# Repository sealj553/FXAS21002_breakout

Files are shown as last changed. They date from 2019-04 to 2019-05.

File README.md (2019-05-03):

# FXAS21002 breakout

This is a modified version of [William Laney's breakout](https://github.com/WLaney/FXAS21002-gyro-PCB) designed to be as small as possible.

Note: The SAO pin is pulled to GND, so the I2C address will be 0x20. If you are using a library that hardcodes the address to 0x21 (Adafruit's for instance), you may need to modify it.

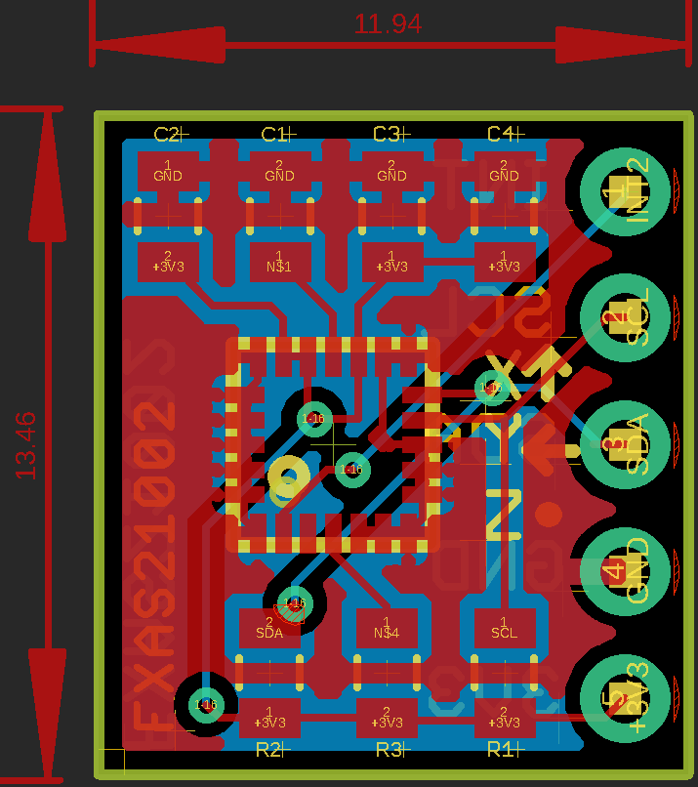
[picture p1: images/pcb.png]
pcb PCB

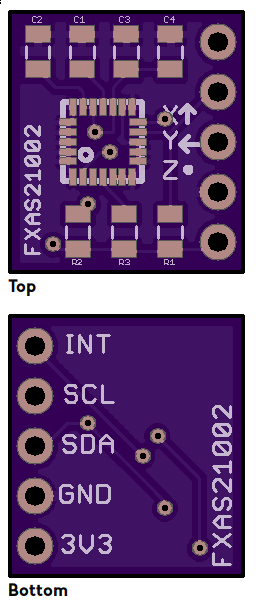
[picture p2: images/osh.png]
osh OSH Park


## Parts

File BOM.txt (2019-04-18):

component/value, size, quanity, digikey part number
--------------------------------------------------------
FXAS21002 IC, 24-TFQFN, 1, FXAS21002CQR1CT-ND
10K resistor, 0805, 2, 311-10.0KCRCT-ND
47k resistor, 0805, 1, 	311-47KARCT-ND
0.1uF capacitor, 0805, 3, 478-3755-1-ND
1.0uF capacitor, 0805, 1 311-1365-1-ND

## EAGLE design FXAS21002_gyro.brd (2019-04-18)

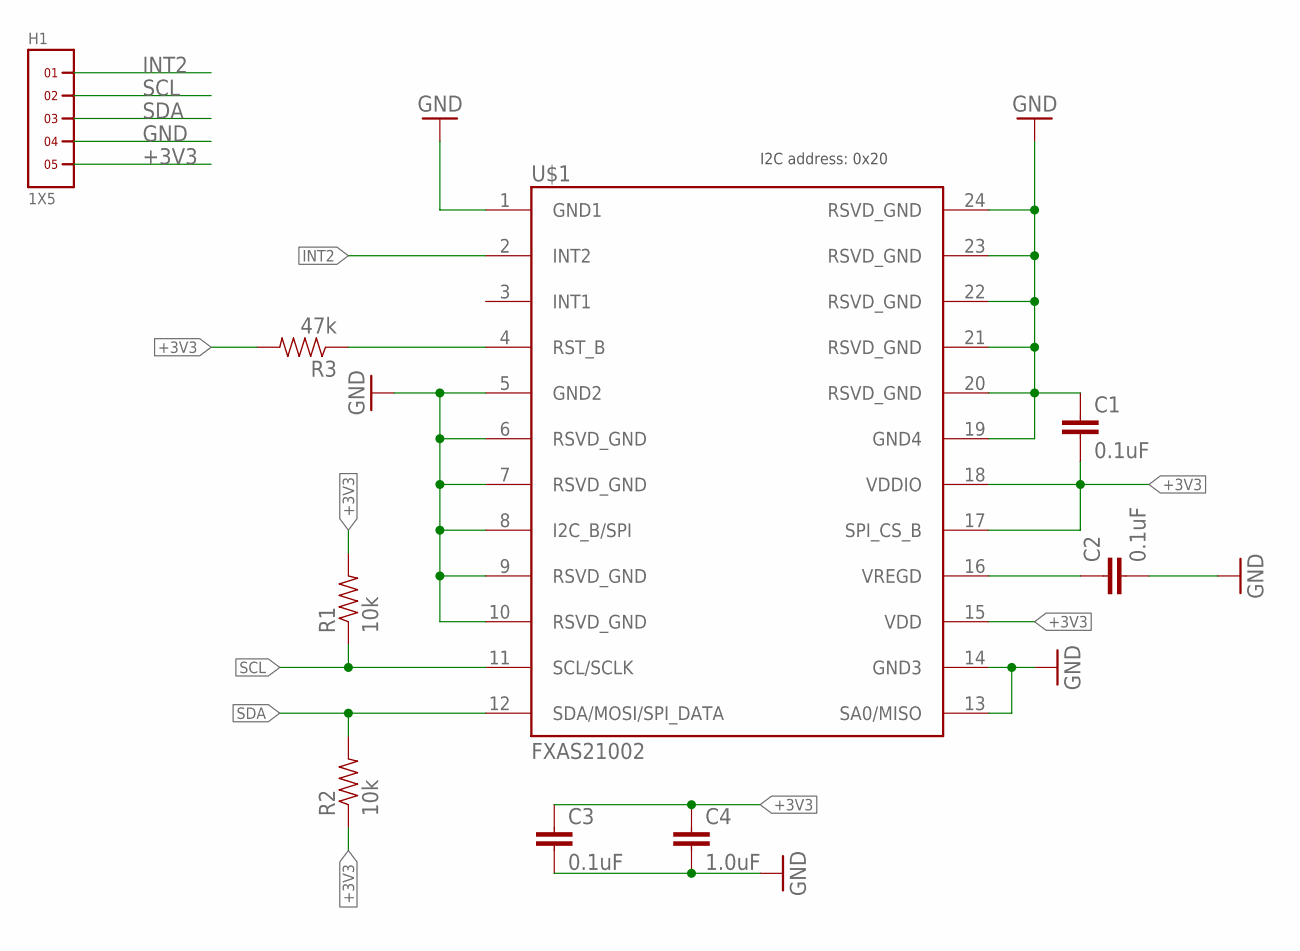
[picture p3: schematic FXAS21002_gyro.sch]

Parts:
C1, C2, C3: 0.1uF; 0805
C4: 1.0uF; 0805
H1: 1X5
R1, R2: 10k; 0805
R3: 47k; 0805
U$1: FXAS21002; 24QFN

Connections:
+3V3: C1.2, C3.1, C4.1, H1.5, R1.2, R2.1, R3.2, U$1.15 (VDD), U$1.17 (SPI_CS_B), U$1.18 (VDDIO)
GND: C1.1, C2.2, C3.2, C4.2, H1.4, U$1.1 (GND1), U$1.5 (GND2), U$1.6 (RSVD_GND), U$1.7 (RSVD_GND), U$1.8 (I2C_B/SPI), U$1.9 (RSVD_GND), U$1.10 (RSVD_GND), U$1.13 (SA0/MISO), U$1.14 (GND3), U$1.19 (GND4), U$1.20 (RSVD_GND), U$1.21 (RSVD_GND), U$1.22 (RSVD_GND), U$1.23 (RSVD_GND), U$1.24 (RSVD_GND)
INT2: H1.1, U$1.2 (INT2)
unnamed: C2.1, U$1.16 (VREGD)
unnamed: R3.1, U$1.4 (RST_B)
SCL: H1.2, R1.1, U$1.11 (SCL/SCLK)
SDA: H1.3, R2.2, U$1.12 (SDA/MOSI/SPI_DATA)

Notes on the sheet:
I2C address: 0x20

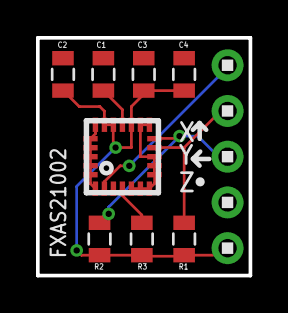
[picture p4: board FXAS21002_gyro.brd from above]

Board: 2 copper layers, 11.8 x 13.2 mm, 9 parts (0 on the bottom side), 7 nets.

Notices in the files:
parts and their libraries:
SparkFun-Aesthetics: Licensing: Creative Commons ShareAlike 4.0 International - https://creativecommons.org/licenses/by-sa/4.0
